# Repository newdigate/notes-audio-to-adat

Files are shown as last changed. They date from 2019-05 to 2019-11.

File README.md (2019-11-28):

# notes-audio-to-adat
* scrapbook for notes for audio-to-opto

# chipsets
## cool-audio
* http://coolaudio.com/docs/COOLAUDIO_V1401_DATASHEET.pdf
* http://coolaudio.com/docs/COOLAUDIO_V1402_DATASHEET.pdf

## wavefront 
* AL1401A
 * [datasheet](http://pdf.datasheetcatalog.com/datasheets2/15/156040_1.pdf)

# ADC
* Cirrus Logic 
  * CS5368-CQZ [datasheet](http://datasheet.octopart.com/CS5368-CQZ-Cirrus-Logic-datasheet-13402503.pdf)

# optical connectors
* TORX147 optical receiver
* PLR135/T10
  * PLR135 Series 2.4 to 5.5 V 16 Mbps 650 nm Photolink Fiber Optic Receiver
    * [snapEDA](https://www.snapeda.com/parts/PLR135/T10/Everlight%20Electronics%20Co%20Ltd/view-part/?ref=search&t=PLR135)
* Toshiba TOTX173
  * [octopart](https://octopart.com/totx173-toshiba-2173863?r=sp&s=UF4sqbTzTXCrdWtcyLfNBw)
  
# logic level converters
* AL1401A uses 5V logic, 3v3 to 5v required
* Texas Instruments 
  * CD40109BNSRG4 [datasheet](https://octopart.com/click/track?ct=datasheets&hlid=24875070&ppid=7109542&sid=370&sig=0583e53)
* The output signal of the AL1401 (i.e. to the fibre-optic LED) is ~0.9V, which needs to be converted to  between 2.5V and 5V5.

# micro-controllers
* xmos
  * XE216-512-TQ128-C20 (	digikey £12.43)

# reference designs
* https://www.xmos.com/download/xCORE-200-Multichannel-Audio-Platform-2V0-Hardware-Manual(1.4).pdf/

# misc links
https://jirin.web.althan.cz/201404-adater-the-lightpipe-interface-for-delta1010-rack/#

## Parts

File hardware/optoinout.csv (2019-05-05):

Qty | Value | Device | Package | Parts | Description | CIIVA_IDS | COMPONENT_LINK_1_DESCRIPTION | COMPONENT_LINK_1_URL | COMPONENT_LINK_3_DESCRIPTION | COMPONENT_LINK_3_URL | DATASHEET | DATASHEET_VERSION | FOOTPRINT_VARIANT_NAME_0 | FOOTPRINT_VARIANT_NAME_1 | FOOTPRINT_VARIANT_NAME_2 | IMPORTED | IMPORTED_FROM | IMPORT_TS | MF | MOUNTING_TECHNOLOGY | MPN | NUMBER_OF_BITS | NUMBER_OF_CHANNELS | NUMBER_OF_OUTPUTS | PACKAGE_DESCRIPTION | PACKAGE_VERSION | PACKING | PREFIX | PROPAGATION_DELAY | RELEASE_DATE | ROHS | TEMPERATURE_RANGE | VAULT_GUID | VAULT_REVISION | VSS
4 |  | PINHD-1X6 | 1X06 | JP1, JP2, JP3, JP4 | PIN HEADER
4 | 0.01uF | C-EUC1206 | C1206 | C10, C12, C23, C24 | CAPACITOR, European symbol
2 | 0.1uF | C-EUC1206 | C1206 | C5, C8 | CAPACITOR, European symbol
3 | 1uF | C-EUC1206 | C1206 | C7, C9, C11 | CAPACITOR, European symbol
1 | 220uF | C-EUC1206 | C1206 | C6 | CAPACITOR, European symbol
1 | 24.576Mhz | XTAL/S | QS | Q1 | CRYSTAL
2 | 39pF C0G | C-EUC1206 | C1206 | C13, C14 | CAPACITOR, European symbol
8 | 4.7uF | C-EUC1206 | C1206 | C15, C16, C17, C18, C19, C20, C21, C22 | CAPACITOR, European symbol
1 | CS5368-2 | CS5368-2 | QFP50P900X900X160-48N | U$3
1 | TEENSY_3.1-3.2_DIL | TEENSY_3.1-3.2_DIL | TEENSY_3.0-3.2&LC_DIL | U$5 | Teensy 3.1 or 3.2 in a DIL Layout.
2 | TEXAS_INSTRUMENTS_CD40109BNSRG4TEXAS_INSTRUMENTS_CD40109BNSRG4_0_0 | TEXAS_INSTRUMENTS_CD40109BNSRG4TEXAS_INSTRUMENTS_CD40109BNSRG4_0_0 | TEXAS_INSTRUMENTS_CD40109BNSRG4_0 | U1, U2 | TI-CD40109B-16 | 1241581 | Manufacturer URL | www.ti.com | Package Specification | http://www.ti.com/lit/ml/msop002a/msop002a.pdf | http://www.ti.com/lit/ds/symlink/cd40109b.pdf | SCHS099B | Level C | Level B | Level A | yes | vault | 1521846607 | Texas Instruments | Surface Mount | CD40109BNSRG4 | 4 | 4 | 4 | 16-Pin Plastic Small Outline Package, Body 10.2 x 5.3 mm, Pitch 1.27 mm | 4040062/C | Tape and Reel | U | 240 ns Max. | 1428502627 | Yes | -55 to 125 degC | 5DE3101F-A9D4-473C-9841-2D565ABC94B0 | 587A32E8-7AA7-4DF0-BE6A-FDFA12492D27 | 3 to 18 V
1 | V1401 | V1401 | SOP20 | U$4

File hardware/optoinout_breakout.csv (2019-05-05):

Qty | Value | Device | Package | Parts | Description | AVAILABILITY | DESCRIPTION | MF | MP | PACKAGE | PRICE
4 |  | PINHD-1X6 | 1X06 | JP1, JP2, JP3, JP4 | PIN HEADER
8 | 100K | R-US_R1206 | R1206 | SI1:R1, SI1:R3, SI2:R1, SI2:R3, SI3:R1, SI3:R3, SI4:R1, SI4:R3 | RESISTOR, American symbol
2 | 100nF | C-EUC1206 | C1206 | C1, C3 | CAPACITOR, European symbol
8 | 10uF | C-EUC1206 | C1206 | SI1:C1, SI1:C2, SI2:C1, SI2:C2, SI3:C1, SI3:C2, SI4:C1, SI4:C2 | CAPACITOR, European symbol
8 | 150 | R-US_R1206 | R1206 | SI1:R2, SI1:R4, SI2:R2, SI2:R4, SI3:R2, SI3:R4, SI4:R2, SI4:R4 | RESISTOR, American symbol
8 | 2700pF | C-EUC1206 | C1206 | SI1:C3, SI1:C4, SI2:C3, SI2:C4, SI3:C3, SI3:C4, SI4:C3, SI4:C4 | CAPACITOR, European symbol
1 | 470R 500mA | EXC3BPL0805 | L0805 | L1 | Chip Bead Core
4 | ACJS-MV-5 | ACJS-MV-5 | ACJS-MV5 | SI1:U$3, SI2:U$3, SI3:U$3, SI4:U$3
1 | PLT133-T10W | PLT133-T10W | PLR135-T10_PLT133-T10W | U$1 | Photo-link Light Transmitter Unit | Unavailable | PLT133 Series 2.7 - 5.5 V 16 Mbps 5.5 mA 680 nm Photo-Link Light Transmitter | Everlight Electronics | PLT133/T10W | DIP-5 Everlight | None

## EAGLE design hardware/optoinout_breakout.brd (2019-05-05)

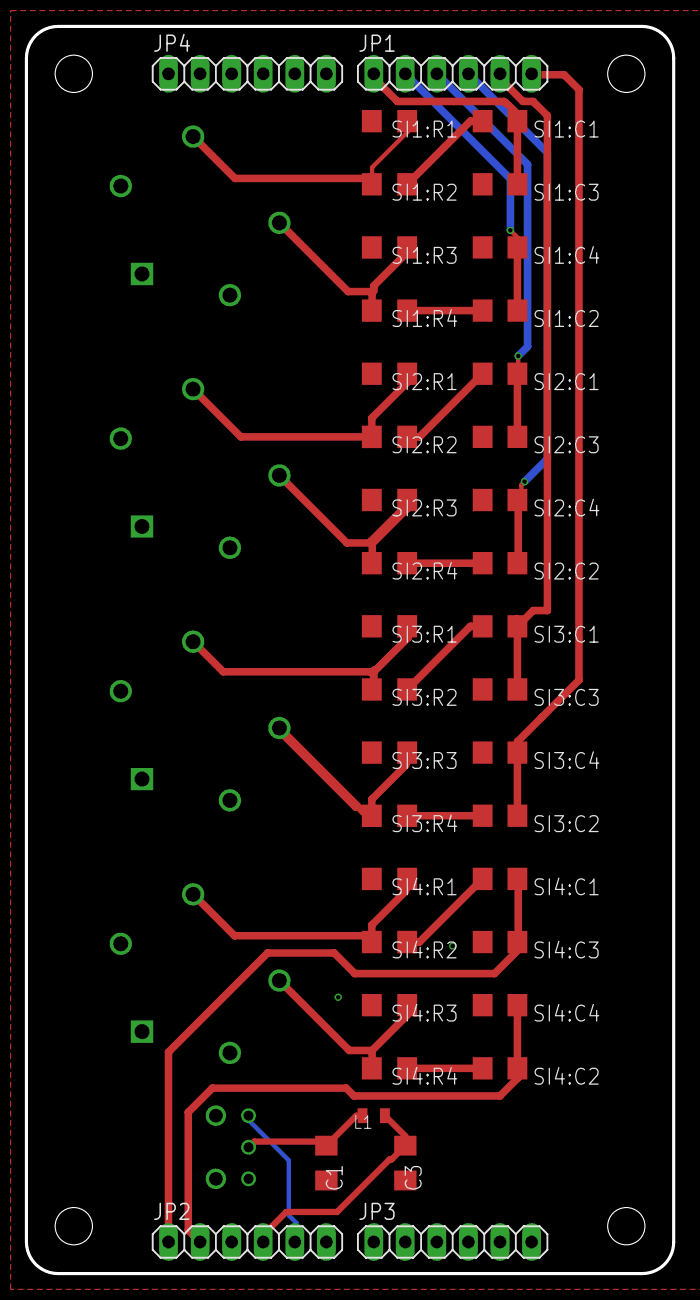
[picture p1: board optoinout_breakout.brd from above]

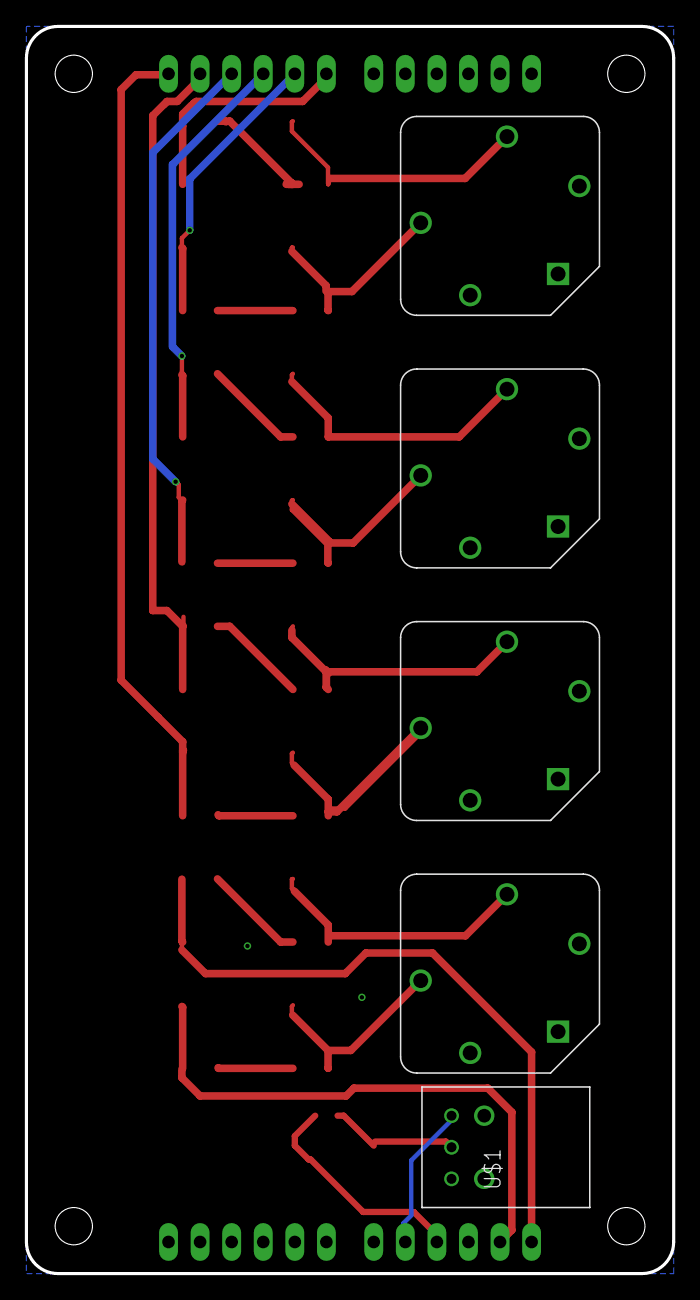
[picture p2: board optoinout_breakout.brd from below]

Board: 2 copper layers, 52.1 x 100.3 mm, 44 parts (5 on the bottom side), 28 nets.

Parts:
C1, C3: 100nF; C1206
JP1, JP2, JP3, JP4: 1X06
L1: 470R 500mA; L0805
SI1:C1, SI1:C2, SI2:C1, SI2:C2, SI3:C1, SI3:C2, SI4:C1, SI4:C2: 10uF; C1206
SI1:C3, SI1:C4, SI2:C3, SI2:C4, SI3:C3, SI3:C4, SI4:C3, SI4:C4: 2700pF; C1206
SI1:R1, SI1:R3, SI2:R1, SI2:R3, SI3:R1, SI3:R3, SI4:R1, SI4:R3: 100K; R1206
SI1:R2, SI1:R4, SI2:R2, SI2:R4, SI3:R2, SI3:R4, SI4:R2, SI4:R4: 150; R1206
SI1:U$3, SI2:U$3, SI3:U$3, SI4:U$3: ACJS-MV-5; ACJS-MV5
U$1: PLT133-T10W; PLR135-T10_PLT133-T10W

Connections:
3V3: C3.1, JP2.4, L1.P$1
AIN1+: JP1.1, SI1:C1.1, SI1:C3.1
AIN2+: JP1.2, SI1:C2.1, SI1:C4.1
AIN3+: JP1.3, SI2:C1.1, SI2:C3.1
AIN4+: JP1.4, SI2:C2.1, SI2:C4.1
AIN5+: JP1.5, SI3:C1.1, SI3:C3.1
AIN6+: JP1.6, SI3:C2.1, SI3:C4.1
AIN7+: JP2.1, SI4:C1.1, SI4:C3.1
AIN8+: JP2.2, SI4:C2.1, SI4:C4.1
GND: C1.2, C3.2, JP2.3, SI1:C3.2, SI1:C4.2, SI1:R1.1, SI1:R3.1, SI1:U$3.P$1, SI1:U$3.P$2, SI1:U$3.P$5, SI2:C3.2, SI2:C4.2, SI2:R1.1, SI2:R3.1, SI2:U$3.P$1, SI2:U$3.P$2, SI2:U$3.P$5, SI3:C3.2, SI3:C4.2, SI3:R1.1, SI3:R3.1, SI3:U$3.P$1, SI3:U$3.P$2, SI3:U$3.P$5, SI4:C3.2, SI4:C4.2, SI4:R1.1, SI4:R3.1, SI4:U$3.P$1, SI4:U$3.P$2, SI4:U$3.P$5, U$1.1
unnamed: C1.1, L1.P$2, U$1.2
OPOUT: JP2.5, U$1.3
SI1:N$1: SI1:R1.2, SI1:R2.1, SI1:U$3.P$4
SI1:N$7: SI1:C1.2, SI1:R2.2
SI1:N$10: SI1:R3.2, SI1:R4.1, SI1:U$3.P$3
SI1:N$11: SI1:C2.2, SI1:R4.2
SI2:N$1: SI2:R1.2, SI2:R2.1, SI2:U$3.P$4
SI2:N$7: SI2:C1.2, SI2:R2.2
SI2:N$10: SI2:R3.2, SI2:R4.1, SI2:U$3.P$3
SI2:N$11: SI2:C2.2, SI2:R4.2
SI3:N$1: SI3:R1.2, SI3:R2.1, SI3:U$3.P$4
SI3:N$7: SI3:C1.2, SI3:R2.2
SI3:N$10: SI3:R3.2, SI3:R4.1, SI3:U$3.P$3
SI3:N$11: SI3:C2.2, SI3:R4.2
SI4:N$1: SI4:R1.2, SI4:R2.1, SI4:U$3.P$4
SI4:N$7: SI4:C1.2, SI4:R2.2
SI4:N$10: SI4:R3.2, SI4:R4.1, SI4:U$3.P$3
SI4:N$11: SI4:C2.2, SI4:R4.2

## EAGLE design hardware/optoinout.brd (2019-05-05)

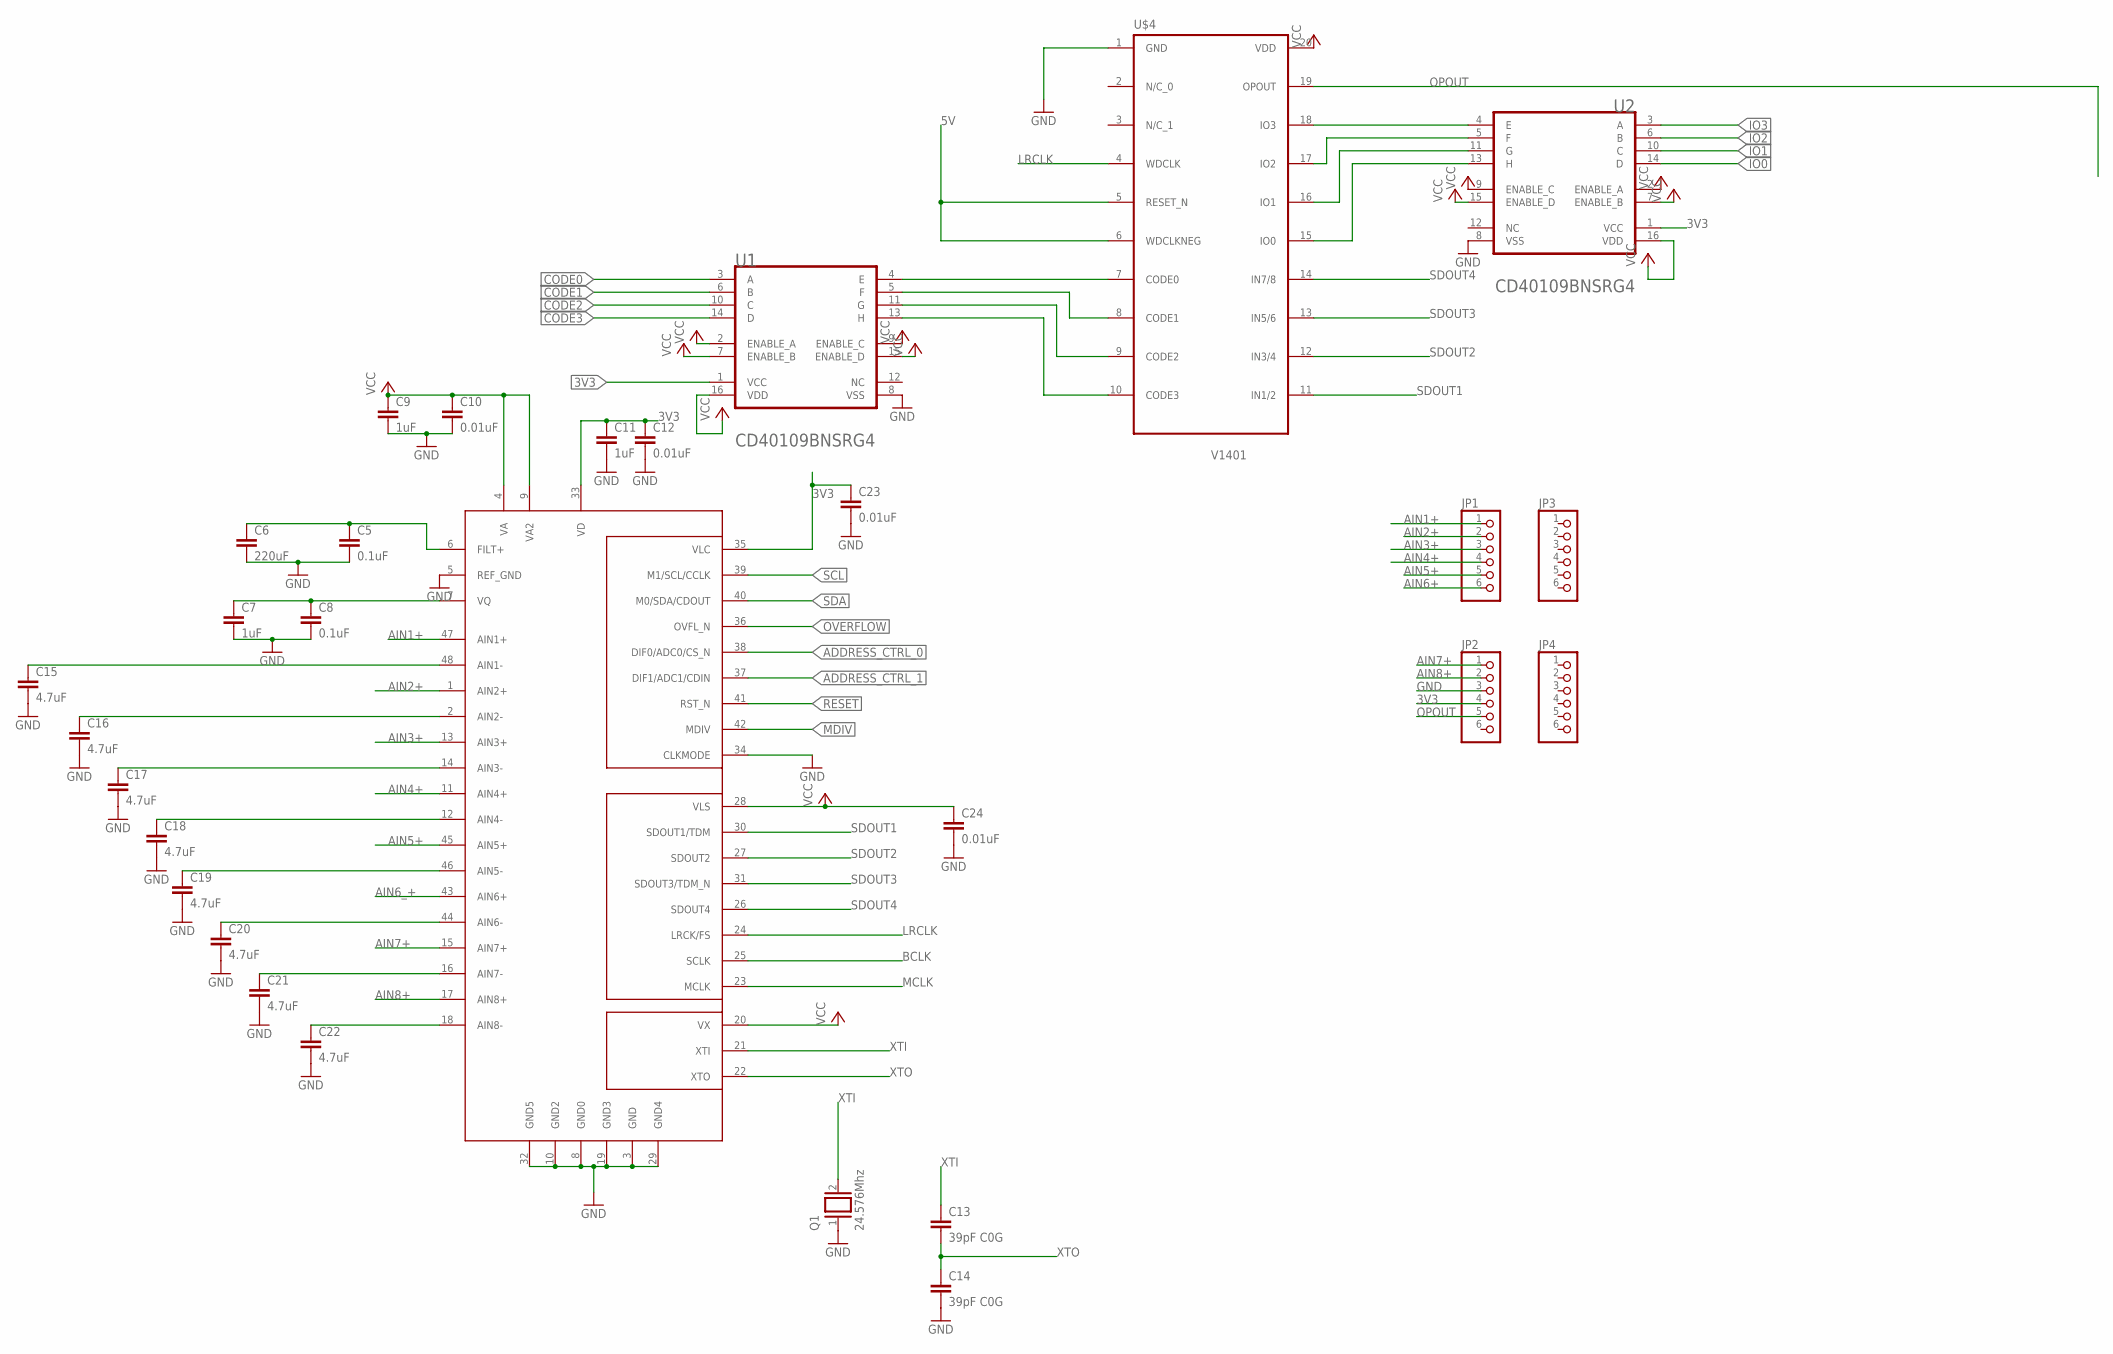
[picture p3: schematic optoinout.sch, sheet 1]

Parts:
C5, C8: 0.1uF; C1206
C6: 220uF; C1206
C7, C9, C11: 1uF; C1206
C10, C12, C23, C24: 0.01uF; C1206
C13, C14: 39pF C0G; C1206
C15, C16, C17, C18, C19, C20, C21, C22: 4.7uF; C1206
JP1, JP2, JP3, JP4: PINHD-1X6; 1X06
Q1: 24.576Mhz; QS
U1, U2: TEXAS_INSTRUMENTS_CD40109BNSRG4TEXAS_INSTRUMENTS_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; TEXAS_INSTRUMENTS_CD40109BNSRG4_0
U$3: CS5368-2; QFP50P900X900X160-48N
U$4: V1401; SOP20

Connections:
3V3: C11.1, C12.1, C23.1, JP2.4, U1.1 (VCC), U2.1 (VCC), U$3.33 (VD), U$3.35 (VLC); also elsewhere on the board
5V: U$4.5 (RESET_N), U$4.6 (WDCLKNEG)
ADDRESS_CTRL_0: U$3.38 (DIF0/ADC0/CS_N); also elsewhere on the board
ADDRESS_CTRL_1: U$3.37 (DIF1/ADC1/CDIN); also elsewhere on the board
AIN1+: JP1.1, U$3.47 (AIN1+)
AIN2+: JP1.2, U$3.1 (AIN2+)
AIN3+: JP1.3, U$3.13 (AIN3+)
AIN4+: JP1.4, U$3.11 (AIN4+)
AIN5+: JP1.5, U$3.45 (AIN5+)
AIN6+: JP1.6
AIN6_+: U$3.43 (AIN6+)
AIN7+: JP2.1, U$3.15 (AIN7+)
AIN8+: JP2.2, U$3.17 (AIN8+)
BCLK: U$3.25 (SCLK)
CODE0: U1.3 (A); also elsewhere on the board
CODE1: U1.6 (B); also elsewhere on the board
CODE2: U1.10 (C); also elsewhere on the board
CODE3: U1.14 (D); also elsewhere on the board
GND: C5.2, C6.2, C7.2, C8.2, C9.2, C10.2, C11.2, C12.2, C14.2, C15.2, C16.2, C17.2, C18.2, C19.2, C20.2, C21.2, C22.2, C23.2, C24.2, JP2.3, Q1.1, U1.8 (VSS), U2.8 (VSS), U$3.3 (GND), U$3.5 (REF_GND), U$3.8 (GND0), U$3.10 (GND2), U$3.19 (GND3), U$3.29 (GND4), U$3.32 (GND5), U$3.34 (CLKMODE), U$4.1 (GND); also elsewhere on the board
IO0: U2.14 (D); also elsewhere on the board
IO1: U2.10 (C); also elsewhere on the board
IO2: U2.6 (B); also elsewhere on the board
IO3: U2.3 (A); also elsewhere on the board
LRCLK: U$3.24 (LRCK/FS), U$4.4 (WDCLK)
MCLK: U$3.23 (MCLK)
MDIV: U$3.42 (MDIV); also elsewhere on the board
unnamed: C7.1, C8.1, U$3.7 (VQ)
unnamed: U1.4 (E), U$4.7 (CODE0)
unnamed: C5.1, C6.1, U$3.6 (FILT+)
unnamed: U1.5 (F), U$4.8 (CODE1)
unnamed: U1.11 (G), U$4.9 (CODE2)
unnamed: U1.13 (H), U$4.10 (CODE3)
unnamed: C16.1, U$3.2 (AIN2-)
unnamed: C15.1, U$3.48 (AIN1-)
unnamed: C17.1, U$3.14 (AIN3-)
unnamed: C18.1, U$3.12 (AIN4-)
unnamed: C19.1, U$3.46 (AIN5-)
unnamed: C20.1, U$3.44 (AIN6-)
unnamed: C21.1, U$3.16 (AIN7-)
unnamed: C22.1, U$3.18 (AIN8-)
unnamed: U2.4 (E), U$4.18 (IO3)
unnamed: U2.5 (F), U$4.17 (IO2)
unnamed: U2.11 (G), U$4.16 (IO1)
unnamed: U2.13 (H), U$4.15 (IO0)
OPOUT: JP2.5, U$4.19 (OPOUT)
OVERFLOW: U$3.36 (OVFL_N); also elsewhere on the board
RESET: U$3.41 (RST_N); also elsewhere on the board
SCL: U$3.39 (M1/SCL/CCLK); also elsewhere on the board
SDA: U$3.40 (M0/SDA/CDOUT); also elsewhere on the board
SDOUT1: U$3.30 (SDOUT1/TDM), U$4.11 (IN1/2)
SDOUT2: U$3.27 (SDOUT2), U$4.12 (IN3/4)
SDOUT3: U$3.31 (SDOUT3/TDM_N), U$4.13 (IN5/6)
SDOUT4: U$3.26 (SDOUT4), U$4.14 (IN7/8)
VCC: C9.1, C10.1, C24.1, U1.2 (ENABLE_A), U1.7 (ENABLE_B), U1.9 (ENABLE_C), U1.15 (ENABLE_D), U1.16 (VDD), U2.2 (ENABLE_A), U2.7 (ENABLE_B), U2.9 (ENABLE_C), U2.15 (ENABLE_D), U2.16 (VDD), U$3.4 (VA), U$3.9 (VA2), U$3.20 (VX), U$3.28 (VLS), U$4.20 (VDD); also elsewhere on the board
XTI: C13.1, Q1.2, U$3.21 (XTI)
XTO: C13.2, C14.1, U$3.22 (XTO)

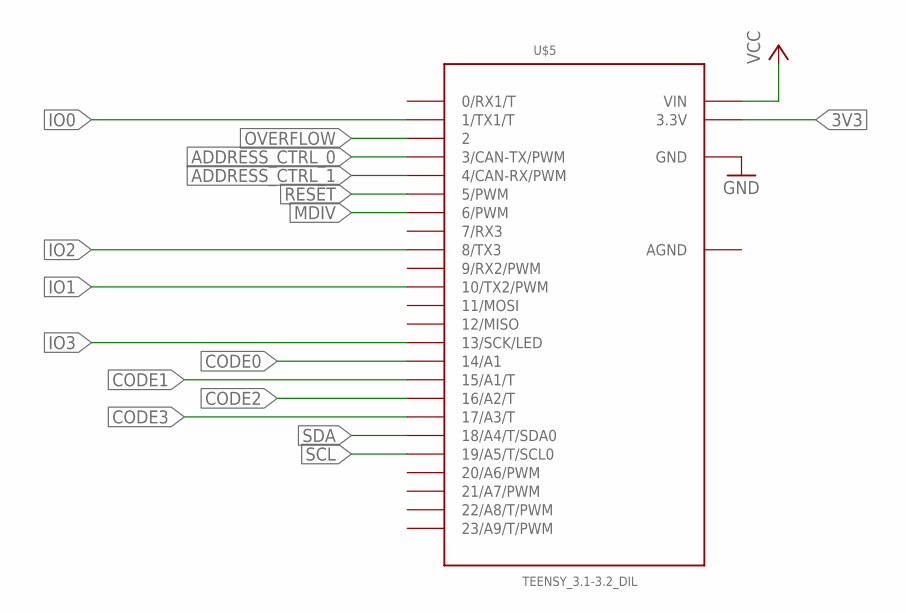
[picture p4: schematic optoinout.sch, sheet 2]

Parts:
U$5: TEENSY_3.1-3.2_DIL; TEENSY_3.0-3.2&LC_DIL

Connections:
3V3: U$5.3.3V; also elsewhere on the board
ADDRESS_CTRL_0: U$5.3 (3/CAN-TX/PWM); also elsewhere on the board
ADDRESS_CTRL_1: U$5.4 (4/CAN-RX/PWM); also elsewhere on the board
AGND: U$5.AGND
CODE0: U$5.14/A0 (14/A1); also elsewhere on the board
CODE1: U$5.15/A1 (15/A1/T); also elsewhere on the board
CODE2: U$5.16/A2 (16/A2/T); also elsewhere on the board
CODE3: U$5.17/A3 (17/A3/T); also elsewhere on the board
GND: U$5.GND; also elsewhere on the board
IO0: U$5.1 (1/TX1/T); also elsewhere on the board
IO1: U$5.10 (10/TX2/PWM); also elsewhere on the board
IO2: U$5.8 (8/TX3); also elsewhere on the board
IO3: U$5.13 (13/SCK/LED); also elsewhere on the board
MDIV: U$5.6 (6/PWM); also elsewhere on the board
OVERFLOW: U$5.2; also elsewhere on the board
RESET: U$5.5 (5/PWM); also elsewhere on the board
SCL: U$5.19/A5 (19/A5/T/SCL0); also elsewhere on the board
SDA: U$5.18/A4 (18/A4/T/SDA0); also elsewhere on the board
VCC: U$5.VIN; also elsewhere on the board

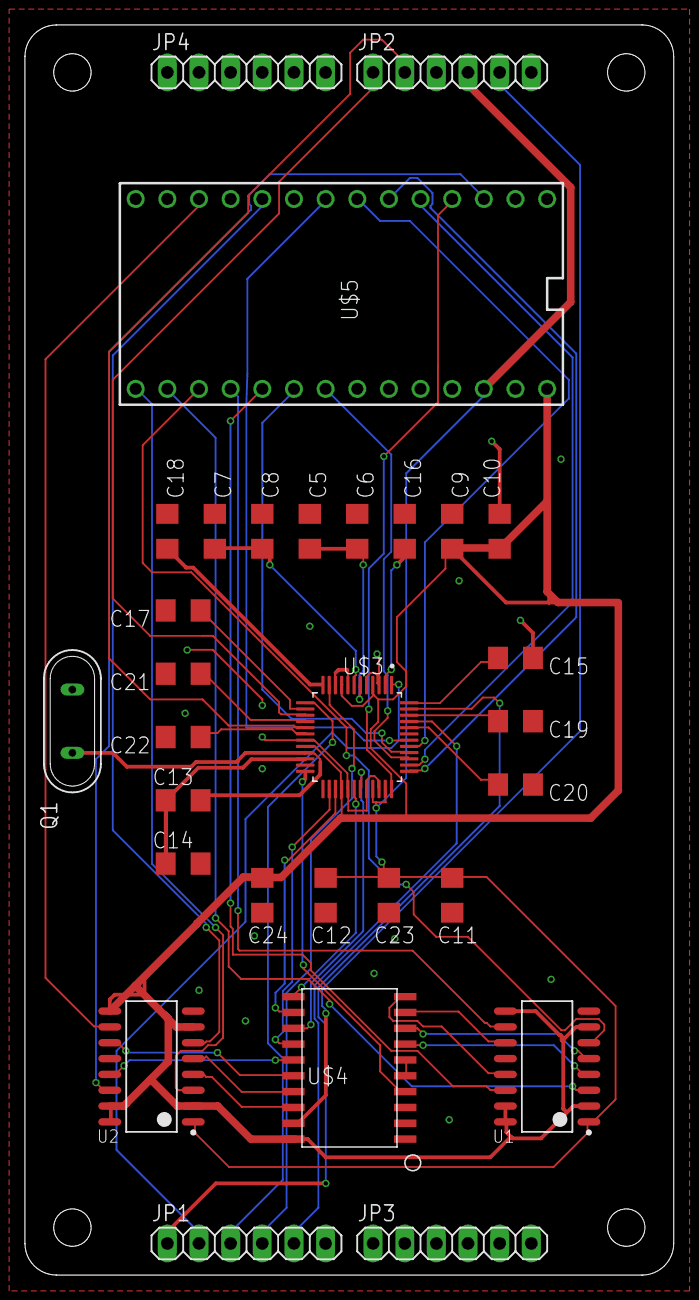
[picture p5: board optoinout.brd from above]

Board: 2 copper layers, 52.1 x 100.3 mm, 30 parts (0 on the bottom side), 52 nets.

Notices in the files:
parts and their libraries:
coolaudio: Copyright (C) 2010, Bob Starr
